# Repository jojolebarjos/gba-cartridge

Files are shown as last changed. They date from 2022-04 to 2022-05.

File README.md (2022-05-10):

# GameBoy Advance cartridge

This project is about making homebrew cartridges for the GameBoy Advance, using an FPGA (here a [TinyFPGA](https://tinyfpga.com/) BX).
Given the update frequency (and the fact that both falling-edges and rising-edges are meaningful), this is more convenient than bit-banging using some micro-controller.
A few experiments are available, some making use of an additional micro-controller (here an [Arduino Nano 33 BLE](https://store.arduino.cc/products/arduino-nano-33-ble)) for communication.

## Cartridge protocol

The cartridge has the following pins:

 * 1: `VCC`, at 3.3V.
 * 2: `PHI`, the physical clock, which can be configured (disabled, 4.19MHz, 8.38MHz, 16.78MHz). Disabled by default. See [waitstate control](https://www.akkit.org/info/gbatek.htm#gbasystemcontrol).
 * 3: `~WR`, write control.
 * 4: `~RD`, read control.
 * 5: `~CS`, select ROM.
 * 6-21: `AD`, address and data.
 * 22-29: `A`, address or data.
 * 30: `CS2`, select SRAM.
 * 31: `IRQ`, interrupt request. Can be left unconnected or grounded.
 * 32: `GND`, ground.

General comments about memory accesses:

 * Data format is always little endian, i.e. least significant byte is first.
 * Depending on the requested (virtual) address and operation, the GameBoy will either assume ROM or RAM when accessing the cartridge.
 * ROM data access is 16-bits, hence data is aligned on 2-bytes steps. This means the implicit least-significant bit of the address is always 0 (i.e. `A0..23` is the address divided by 2).
 * ARM instructions (32-bits) are slow to fetch. It is better to use THUMB instructions, or copy the code in WRAM.
 * GamePak accesses can be either sequential or non-sequential. The first access to a random location in ROM must be non-sequential.
 * The GameBoy will wait a few cycles when accessing memory. Up to 3 configurations can be used (useful if the cartridge has multiple ROM units with different physical properties). By default, it will assume 4 cycles for random access, and then 2 cycles for sequential access. See [waitstate control](https://www.akkit.org/info/gbatek.htm#gbasystemcontrol).
 * When doing ROM access, the `AD` bus is used in both direction. The cartridge should actively write only when both `~CS` and `~RD` are low.
 * When doing RAM access, the `AD` bus is used for the 16-bits address, and the 8-bits data is returned through `A16..23`. `~CS2` is used instead of `~CS`.

A read access from the ROM is done as follows:

 * On `~CS` falling-edge, the cartridge latches A0-A23 as address.
 * On `~RD` falling-edge, the cartridge fetches the data at latched address and outputs D0-D15. The output must be ready by next rising-edge of `~RD` (depends on waitstates).
 * On `~RD` rising-edge, the cartridge increments latched address by one (i.e. allow sequential read by just strobing `~RD`).
 * On `~CS` rising-edge, the transaction is done.

While it usually makes no sense to write to a ROM, the GameBoy will submit write commands in a similar fashion, toggling `~WR` instead.
In this project, we use that to let the software write back to the cartridge, for instance to report key input.

Therefore, a simple read-only GamePak ROM does not use `PHI`, `~WR`, `~CS2` and `IRQ`.

Cartridges that require more than 64K of storage will need to use bank switching to map more memory.
This topic has not been investigated in this project.

Relevant links:

 * References
   * https://github.com/gbadev-org/awesome-gbadev
   * https://www.gbadev.org/
   * https://www.akkit.org/info/gbatek.htm
   * https://problemkaputt.de/gbatek.htm
   * http://www.hardwarebook.info/Game_Pak
 * Blogs and websites
   * https://gekkio.fi/
     * https://gekkio.fi/files/gb-docs/gbctr.pdf
     * https://github.com/gekkio/gb-hardware
   * https://www.darkfader.net/gba/
     * http://files.darkfader.net/gba/files/cartridge.txt
   * https://reinerziegler.de.mirrors.gg8.se/GBA/gba.htm
   * http://kylehalladay.com/blog/tutorial/gba/2017/04/18/GBA-By-Example-4.html
   * https://fabiensanglard.net/another_world_polygons_GBA/
   * https://github.com/PeterLemon/GBA
 * Custom cartridges
   * https://github.com/uXeBoy/GBA
   * https://github.com/uXeBoy/GBArduboy
   * http://www.dl9sec.de/prj_gbacart.html
 * Cartridge reader
   * https://www.insidegadgets.com/2011/03/19/gbcartread-arduino-based-gameboy-cart-reader-%E2%80%93-part-1-read-the-rom/
   * https://douevenknow.us/post/68126856498/arduino-based-gba-rom-dumper-part-1
   * https://dragaosemchama.com/en/2015/12/gameboy-pak-reader-cartridge-header/
   * https://mgba.io/2015/10/20/dumping-the-undumped/
 * Multiboot-based
   * https://github.com/Shyri/gba-bt-hid
 * Old GameBoy, but still very interesting
   * https://dhole.github.io/post/gameboy_cartridge_emu_1/
   * https://retrocomputing.stackexchange.com/questions/11732/how-does-the-gameboys-memory-bank-switching-work
   * https://github.com/dwaq/Homebrew-Gameboy-Cartridge
   * https://www.insidegadgets.com/2018/04/18/building-a-2mb-mbc5-gameboy-cart-part-1-cpld-as-the-mbc-and-adding-flash-as-our-rom/
   * http://bitwise.bperki.com/2018/08/08/custom-game-boy-cartridge-project-update-1/
   * https://wiki.tauwasser.eu/view/MBC1
   * https://catskull.net/gameboy-boot-screen-logo.html

## Compiling a GameBoy Advance game

The GameBoy Advance features an ARM-based processor.
We will use [devkitPro](https://devkitpro.org/wiki/Main_Page) to compile binaries.

The most straightforward approach is to use the [Docker image](https://github.com/devkitPro/docker).
We share the local folder with the container, to avoid unnecessary copies.

```
# Run in interactive mode
docker run -ti -v ${PWD}:/rom devkitpro/devkitarm
# On Windows: docker run -ti -v %cd%:/rom devkitpro/devkitarm

# Add compiler binaries to path
export PATH="/opt/devkitpro/devkitARM/bin/:$PATH"

# Go to shared folder and build files
cd /rom/
make
```

Links related to GBA software development:

 * https://www.coranac.com/tonc/text/toc.htm
 * https://devkitpro.org/wiki/Getting_Started
 * https://github.com/devkitPro/docker
 * https://github.com/devkitPro/gba-examples
 * http://kylehalladay.com/blog/tutorial/gba/2017/03/28/GBA-By-Example-1.html
 * https://www.coranac.com/tonc/text/setup.htm#sec-dkp
 * https://www.akkit.org/info/gbatek.htm#gbakeypadinput
 * https://www.coranac.com/tonc/text/keys.htm
 * https://github.com/felixjones/gba-plusplus

Emulators and GameBoy implementations:

 * https://mgba.io/
 * https://github.com/RobertPeip/FPGBA
 * https://github.com/AntonioND/giibiiadvance
 * https://mitxela.com/projects/swotgb/about

## Development PCB

In order to have a flexible playground, a custom-made PCB has been designed using [KiCad](https://www.kicad.org/) and ordered on [JLCPCB](https://jlcpcb.com/).
[This](https://www.aliexpress.com/item/1005003412771520.html) cheap cartridge header can be soldered to connect an actual cartridge, if needed.
A simple casing has been designed using [FreeCAD](https://www.freecadweb.org/) and 3D-printed (resin) to properly fit the GameBoy Advance.
Depending on whether a GameBoy Advance and/or a cartridge is used, the FPGA can have various roles.

 * The 32 pins of the cartridge are forwarded from the GameBoy to the cartridge.
 * Two sets of connectors are available to intercept (or drive) the pins: a 2x16 header for generic usage, and a 2x14 header designed to hold the TinyFPGA BX.
 * A dedicated header is available to configure power supply.
 * `A` is not exposed to the TinyFPGA BX, as there are not enough pins. Note that some GPIO pins are exposed as pads by the FPGA, but this is not convenient for this project.
 * Instead, some pins are exposed as "extra", and can be used either for external communication (e.g. SPI) or connected to `A` to extend the address space.
 * Use ENIG finish (i.e. *not* HASL), for more strength.
 * In order to fit in the opening, a thickness of 0.8mm should be used (as the casing already takes roughly 1mm).

See the [schema](pcb.sch.pdf) for more details.

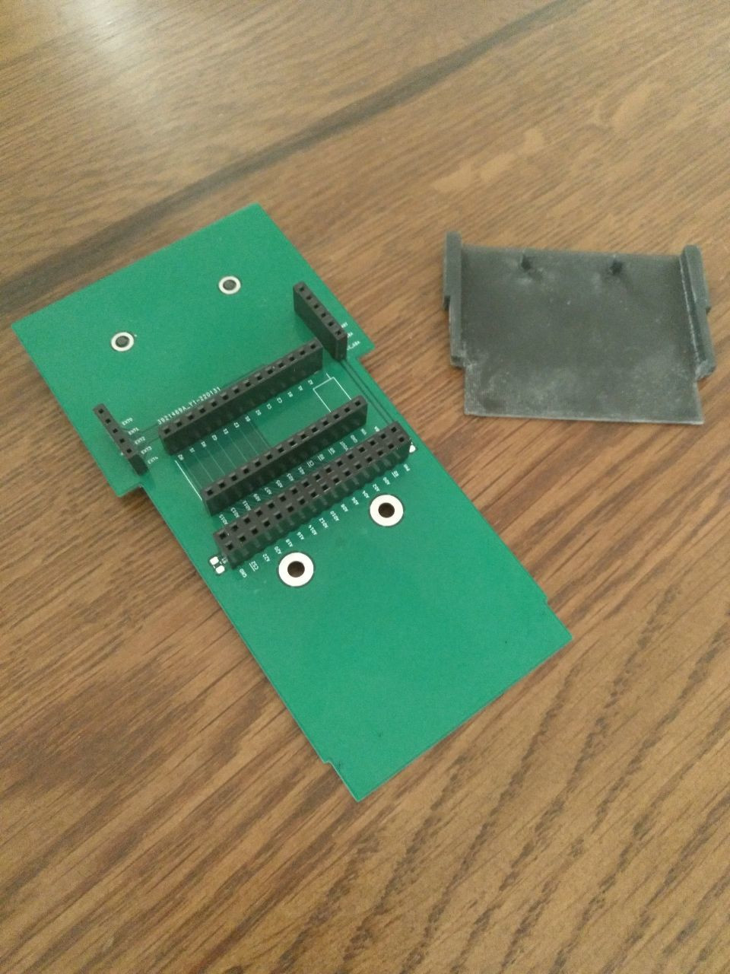
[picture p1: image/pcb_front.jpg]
PCB (front)


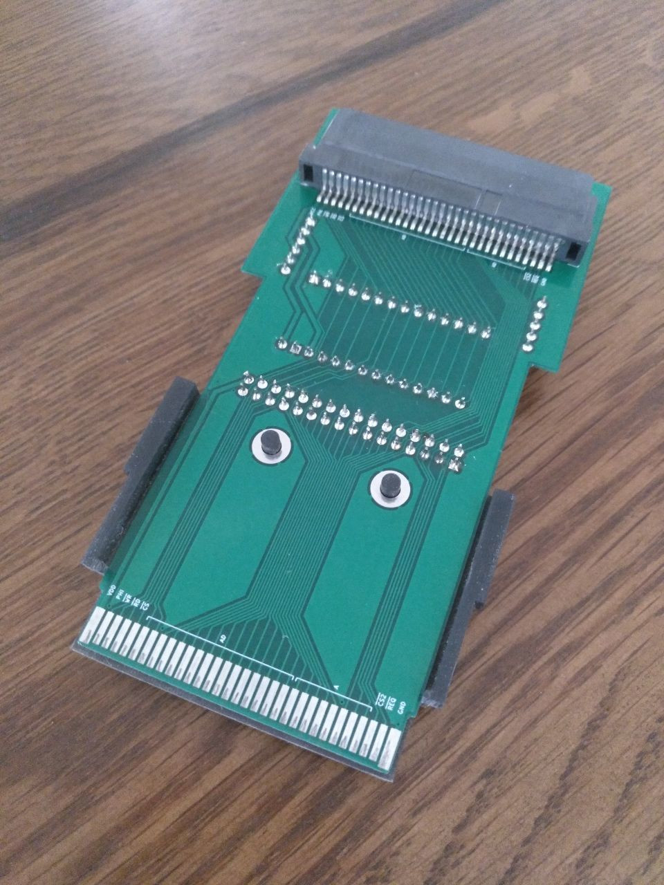
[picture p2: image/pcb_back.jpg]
PCB (back)


## Getting started with TinyFPGA BX

As described in the [User Guide](https://tinyfpga.com/bx/guide.html), install [APIO](https://github.com/FPGAWARS/apio):

```
conda create -n fpga python=3.7
activate fpga
pip install apio==0.4.0b5 tinyprog
apio install system scons icestorm iverilog
```

Connect the board and run:

```
apio install drivers
apio drivers --serial-enable
```

Reconnect the board, and check that the device is recognized.
Windows might take a few seconds to actually detect and properly setup the serial device.

```
apio system --lsserial
```

Make sure the board is up-to-date:

```
tinyprog --update-bootloader
```

For better integration, use [Atom](https://atom.io/) and install the `apio-ide` package.
Note that you should run Atom inside the Conda environment, so that paths are properly set up:

```
atom --new-instance
```

Using the [default template](https://github.com/tinyfpga/TinyFPGA-BX/tree/master/apio_template), you can quickly start developing the TinyFPGA.

Note that you can upload the code by calling `tinyprog` directly:

```
tinyprog --program hardware.bin
```

The `apio-ide` package provide shortcuts for the most common operations, i.e. build and program.
Use `F8` to show the compilation log after a successful build.

Links:

 * https://tinyfpga.com/
 * http://www.clifford.at/icestorm/
 * https://www.youtube.com/watch?v=ZNunxg7o8l0
 * https://hackaday.io/project/159191-fpga-bootcamp-1
 * https://github.com/YosysHQ/nextpnr

## Experiments

A few simple experiments have been made until now.

### Cartridge dump

An Arduino Nano 33 BLE is connected to a TinyFPGA BX over SPI.

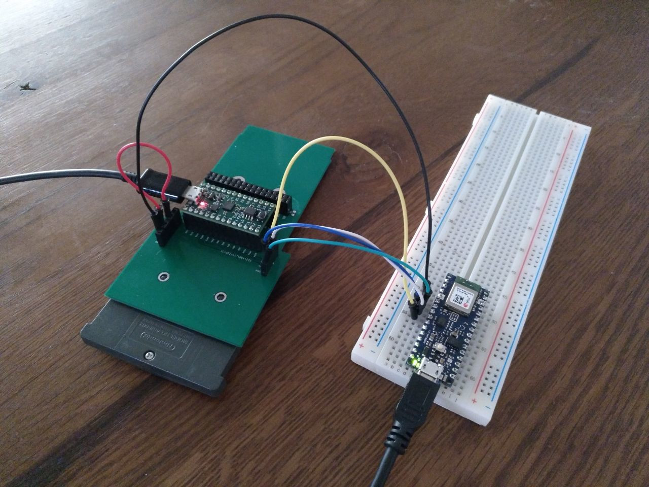
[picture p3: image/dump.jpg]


| Name | Arduino Nano 33 BLE | Wire | Board | TinyFPGA BX |
| ---- | ---- | ---- | ---- | ---- |
| GND | GND | black | GND | GND | GND |
| MISO | D2 (2) | green | EXT0 | 1 (A2) |
| MOSI | D3 (3) | blue | EXT1 | 2 (A1) |
| SCK | D4 (4) | white | EXT2 | 3 (B1) |
| SS | D5 (5) | yellow | EXT3 | 4 (C2) |

The cartridge is powered by the TinyFPGA BX, i.e. `VCC_CART` is connected to `VOUT`.

This is a naive implementation of the above-mentioned protocol:

 * The FPGA toggles `~CS` and `~RD`, writes the address and reads the output through `AD`. Note that, as `A` is ignored, only the first 131072 can be read.
 * The Arduino acts as a bridge, communicating with the FPGA using SPI and with the computer using USB.
 * A Python script sends the commands and dumps the content to a binary file.

Note that this approach does not handle any memory bank.
Therefore, it cannot be used as-is to dump a whole cartridge.

See [`./experiments/dump/`](./dump/) for more details.

### Read-only cartridge

The TinyFPGA BX acts as a read-only ROM cartridge.
A simple "game" is provided, where a white dot is moved using the arrows.

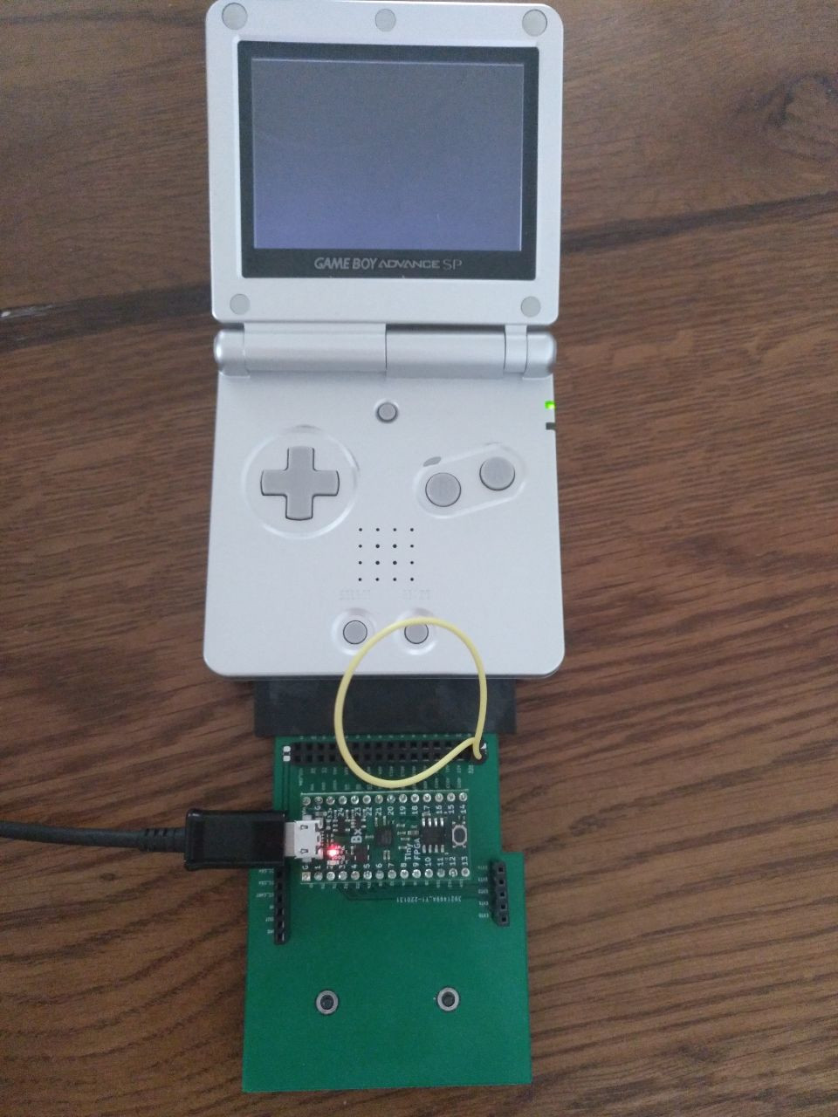
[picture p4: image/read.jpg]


See [`./experiments/read/`](./read/) for more details.

### Read-write

The TinyFPGA BX acts as a writable ROM cartridge.
A simple "game" is provided, where buttons are written at each frame to the cartridge memory.

See [`./experiments/write/`](./write/) for more details.

### USB gamepad

The TinyFPGA BX acts as a writable ROM cartridge.
A simple "game" is provided, where buttons are written at each frame to the cartridge memory.
This information is then forwarded to an Arduino Nano 33 BLE, which is recognized as a HID gamepad.

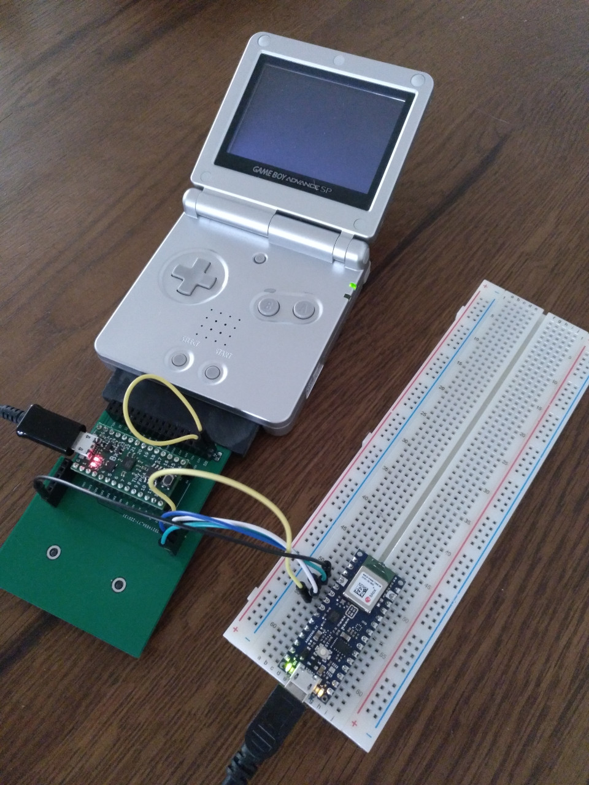
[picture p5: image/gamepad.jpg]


TODO: use HID over USB/BLE

TODO: use interrupts on GBA (and sleep when no button is pressed)

TODO: make FPGA the SPI master, or use interrupts to let the Arduino communicate only when needed

See [`./experiments/gamepad/`](./gamepad/) for more details.

### Direct Memory Access

...

http://problemkaputt.de/gbatek-gba-dma-transfers.htm
https://gbdev.gg8.se/wiki/articles/Video_Display
https://austinjadams.com/blog/autograding-gba-dma/
https://badd10de.dev/notes/gba-programming.html

See [`./experiments/dma/`](./dma/) for more details.

### VGA

The GBA has a TFT color LCD that is 240 x 160 pixels in size and has a refresh rate of exactly 280896 cpu cycles per frame, or around 59.73 hz.
Most GBA programs will need to structure themselves around this refresh rate.
The LCD can display 15-bit RGB colors (0bxbbbbbgggggrrrrr).

TODO:
 * Use backbuffer (with palette) mode 4, to acquire next frame during previous one is drawn
 * VGA is an analog signal, with 5 (+GND) relevant pins: R, G, B, H-Sync, V-Sync
 * We can naively connect these to digital inputs, effectively displaying only 8 colors
 * We can also use an analog-to-digital serial converter, if FPGA is fast enough
 * https://electronics.stackexchange.com/questions/134674/how-vga-monitor-detects-video-resolution
 * Need 3:2 resolution, so maybe use 320x200 and trim 20 pixels horizontally? https://www.videotechnology.com/0904/formats.html

The closest standard mode is 720x480 @60Hz RGB 4:4:4

 * https://en.wikipedia.org/wiki/Video_Graphics_Array
 * https://en.wikipedia.org/wiki/HDMI
 * https://www.youtube.com/watch?v=l7rce6IQDWs&ab_channel=BenEater
 * http://tinyvga.com/vga-timing
 * https://ez.analog.com/cfs-file/__key/telligent-evolution-components-attachments/00-317-00-00-00-05-21-37/HDMISpecification13a.pdf
 * https://forum.digikey.com/t/vga-controller-vhdl/12794

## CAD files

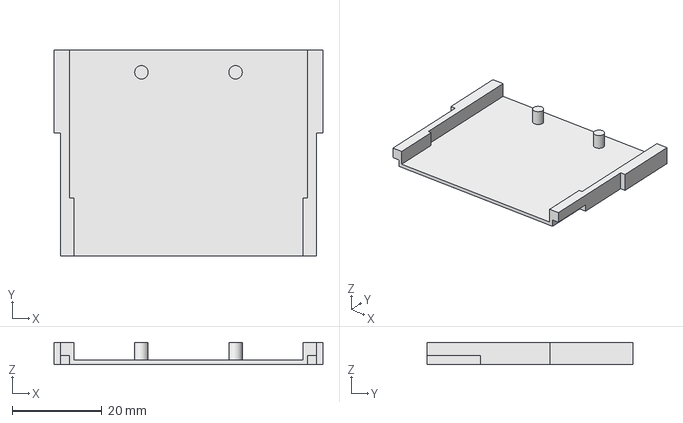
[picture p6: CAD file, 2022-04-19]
case/case.FCStd
60.0 x 46.0 x 5.00 mm

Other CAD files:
case/case.stl

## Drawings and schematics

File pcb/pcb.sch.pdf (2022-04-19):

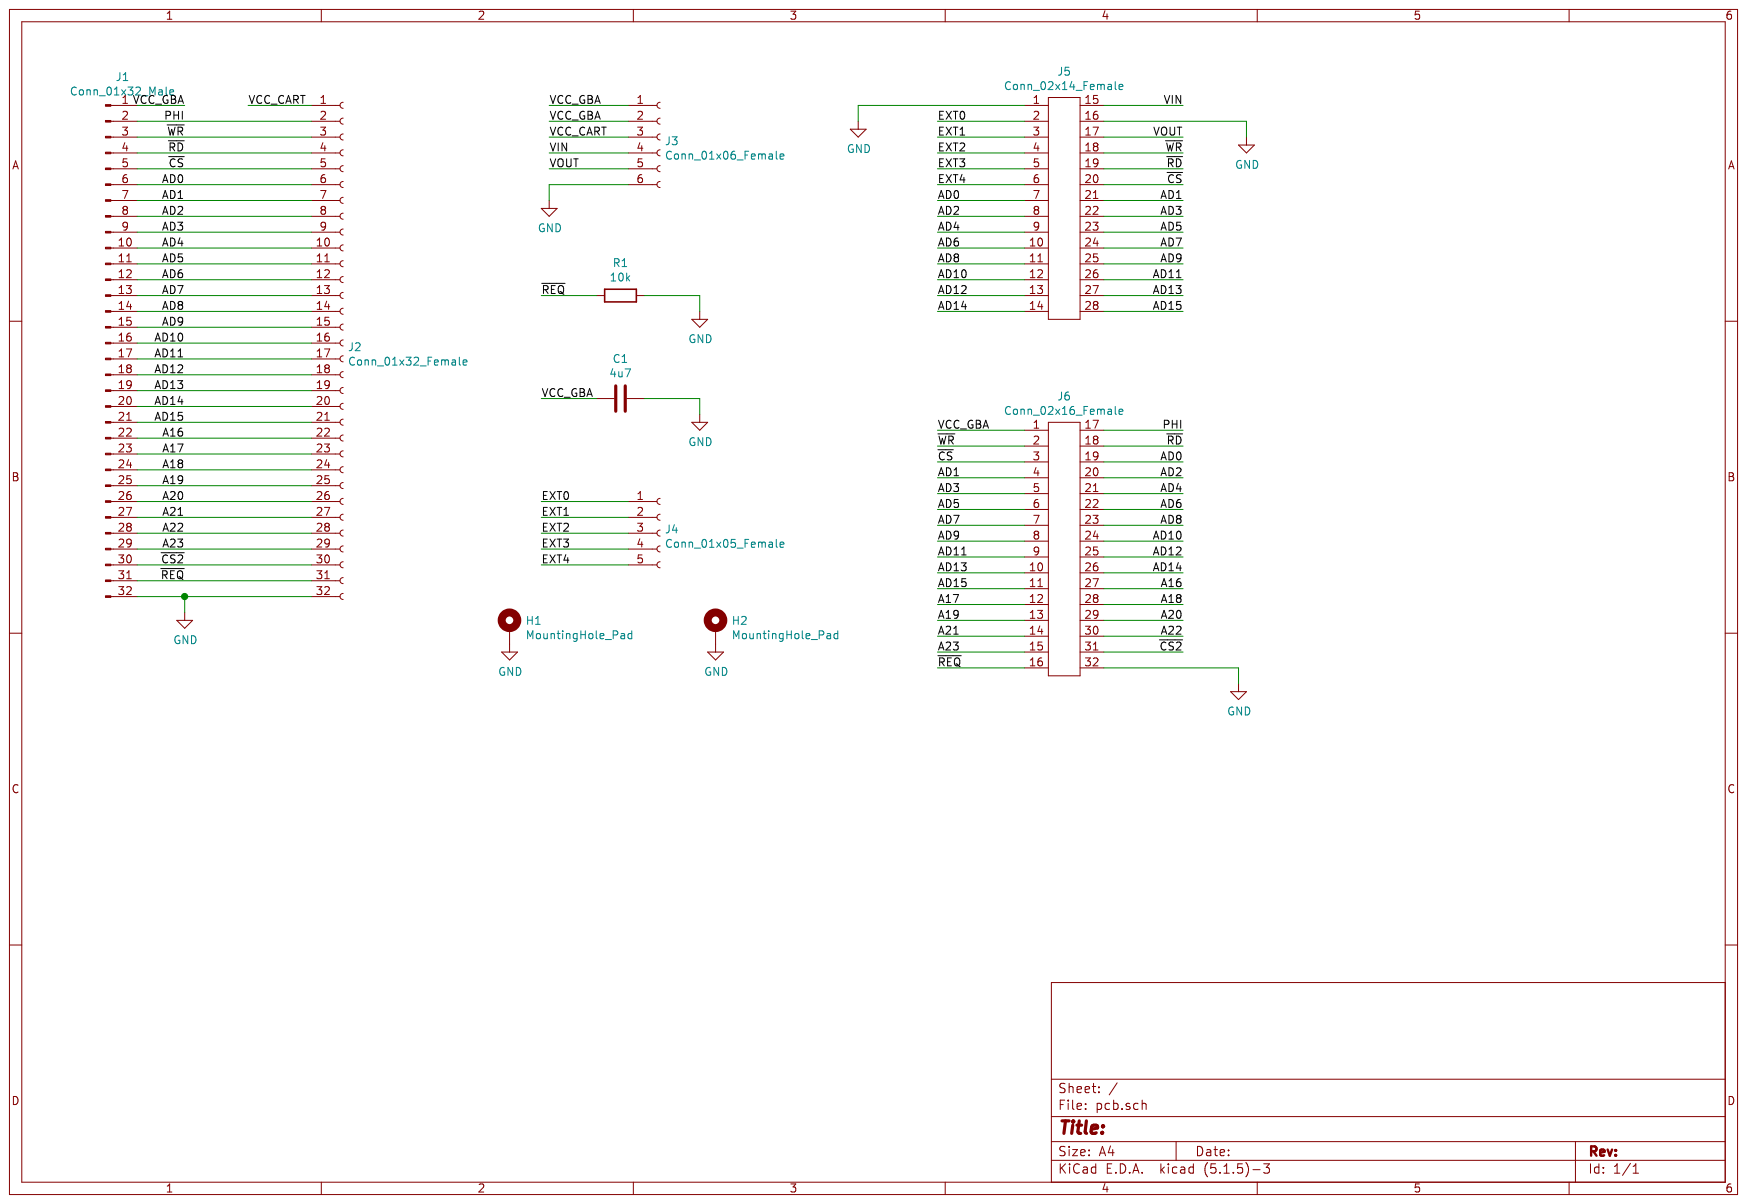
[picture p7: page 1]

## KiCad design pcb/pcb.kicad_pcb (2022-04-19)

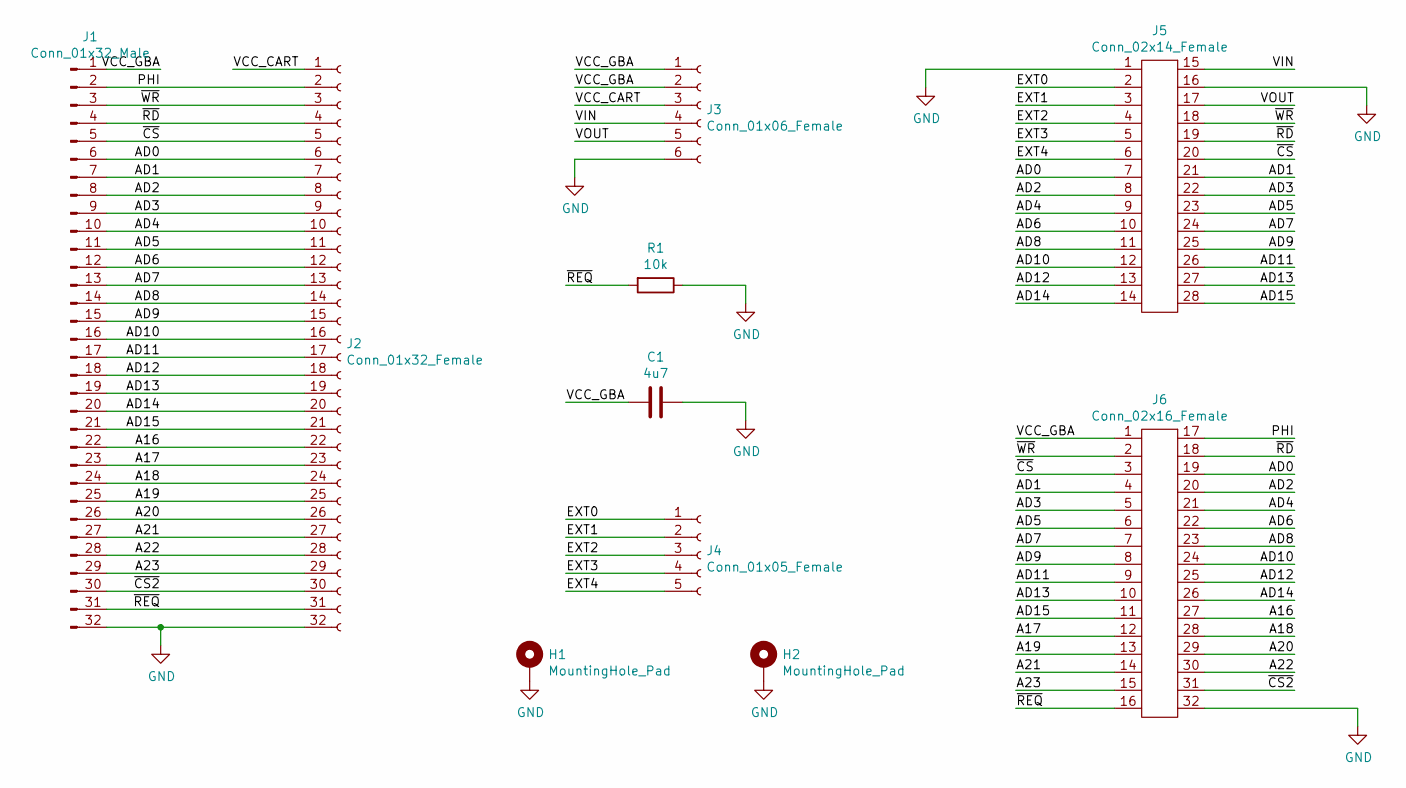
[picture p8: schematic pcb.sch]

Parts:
C1: 4u7; C_0805_2012Metric_Pad1.15x1.40mm_HandSolder
H1, H2: MountingHole_Pad; MountingHole_3.2mm_M3_Pad
J1: Conn_01x32_Male; GBA
J2: Conn_01x32_Female; CART
J3: Conn_01x06_Female; PinHeader_Power
J4: Conn_01x05_Female; PinHeader_Extra
J5: Conn_02x14_Female; PinHeader_TinyFPGA_BX
J6: Conn_02x16_Female; PinHeader_Secondary
R1: 10k; R_0805_2012Metric_Pad1.15x1.40mm_HandSolder

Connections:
/A16: J1.22, J2.22, J6.27
/A17: J1.23, J2.23, J6.12
/A18: J1.24, J2.24, J6.28
/A19: J1.25, J2.25, J6.13
/A20: J1.26, J2.26, J6.29
/A21: J1.27, J2.27, J6.14
/A22: J1.28, J2.28, J6.30
/A23: J1.29, J2.29, J6.15
/AD0: J1.6, J2.6, J5.7, J6.19
/AD1: J1.7, J2.7, J5.21, J6.4
/AD2: J1.8, J2.8, J5.8, J6.20
/AD3: J1.9, J2.9, J5.22, J6.5
/AD4: J1.10, J2.10, J5.9, J6.21
/AD5: J1.11, J2.11, J5.23, J6.6
/AD6: J1.12, J2.12, J5.10, J6.22
/AD7: J1.13, J2.13, J5.24, J6.7
/AD8: J1.14, J2.14, J5.11, J6.23
/AD9: J1.15, J2.15, J5.25, J6.8
/AD10: J1.16, J2.16, J5.12, J6.24
/AD11: J1.17, J2.17, J5.26, J6.9
/AD12: J1.18, J2.18, J5.13, J6.25
/AD13: J1.19, J2.19, J5.27, J6.10
/AD14: J1.20, J2.20, J5.14, J6.26
/AD15: J1.21, J2.21, J5.28, J6.11
/EXT0: J4.1, J5.2
/EXT1: J4.2, J5.3
/EXT2: J4.3, J5.4
/EXT3: J4.4, J5.5
/EXT4: J4.5, J5.6
/PHI: J1.2, J2.2, J6.17
/VCC_CART: J2.1, J3.3
/VCC_GBA: C1.2, J1.1, J3.1, J3.2, J6.1
/VIN: J3.4, J5.15
/VOUT: J3.5, J5.17
/~CS: J1.5, J2.5, J5.20, J6.3
/~CS2: J1.30, J2.30, J6.31
/~RD: J1.4, J2.4, J5.19, J6.18
/~REQ: J1.31, J2.31, J6.16, R1.2
/~WR: J1.3, J2.3, J5.18, J6.2
GND: C1.1, H1.1, H2.1, J1.32, J2.32, J3.6, J5.1, J5.16, J6.32, R1.1

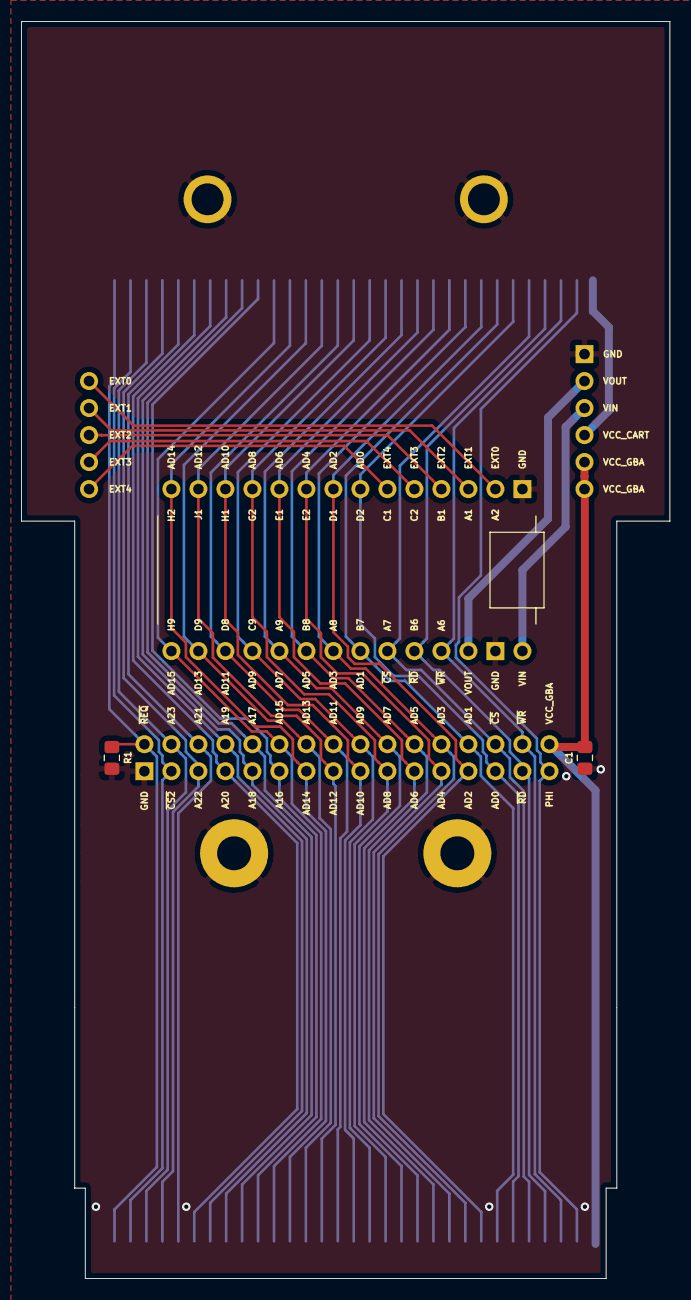
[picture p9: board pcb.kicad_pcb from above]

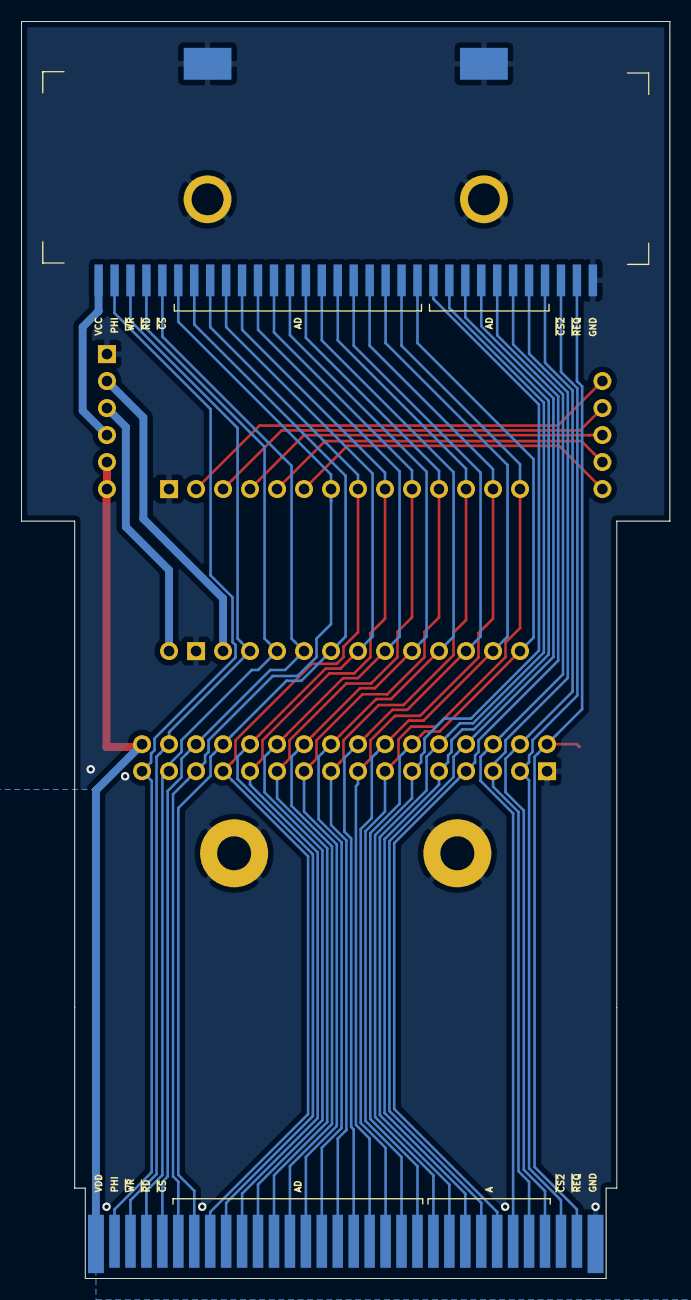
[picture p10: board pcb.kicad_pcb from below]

Board: 2 copper layers, 61.0 x 118.2 mm, 10 parts (2 on the bottom side), 40 nets.

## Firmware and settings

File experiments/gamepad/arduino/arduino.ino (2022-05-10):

// TODO use https://os.mbed.com/docs/mbed-os/v6.15/apis/spi.html instead

// Pins
#define MISO 2
#define MOSI 3
#define SCK 4
#define SS 5

// GameBoy Advance key state
uint16_t keyinput = 0x0000;

void setup() {

  // Connect to USB serial port
  Serial.begin(9600);
  while (!Serial);

  // Configure pins
  pinMode(MISO, INPUT);
  pinMode(MOSI, OUTPUT);
  pinMode(SCK, OUTPUT);
  pinMode(SS, OUTPUT);
  digitalWrite(MOSI, LOW);
  digitalWrite(SCK, LOW);
  digitalWrite(SS, HIGH);
}

uint16_t transfer(uint16_t in) {

  // Set Slave Select to low, to start message
  digitalWrite(SCK, LOW);
  digitalWrite(LED_BUILTIN, LOW);
  digitalWrite(SS, LOW);

  // Exchange each bit, most significant bit first
  int out = 0;
  for (int b = 15; b >= 0; --b) {

    // Write bit at Serial Clock falling edge
    int b_in = (in >> b) & 1;
    digitalWrite(MOSI, b_in ? HIGH : LOW);

    // Wait half-cycle
    delay(1);

    // Rise Serial Clock
    digitalWrite(SCK, HIGH);
    digitalWrite(LED_BUILTIN, HIGH);

    // Read bit at rising edge
    int b_out = digitalRead(MISO) == HIGH ? 1 : 0;
    out = (out << 1) | b_out;

    // Wait half-cycle
    delay(1);

    // Fall Serial Clock
    digitalWrite(SCK, LOW);
    digitalWrite(LED_BUILTIN, LOW);
  }

  // Set Slave Select to high, to end message
  digitalWrite(SS, HIGH);
  return out;
}

void loop() {

  // Read from SPI
  // Note: slave ignores the actual data, so let us just use zero
  uint16_t out = transfer(0x0000);

  // If state did change, notify
  if (out != keyinput) {
    keyinput = out;
    // TODO do an actual USB/BLE gamepad interface
    Serial.println(keyinput);
  }

  // Wait a bit, to avoid spam
  delay(2);
}

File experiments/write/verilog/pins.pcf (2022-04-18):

###############################################################################
#
# TinyFPGA BX constraint file (.pcf)
#
###############################################################################
#
# Copyright (c) 2018, Luke Valenty
# All rights reserved.
#
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
# THIS SOFTWARE IS PROVIDED BY THE COPYRIGHT HOLDERS AND CONTRIBUTORS "AS IS" AND
# ANY EXPRESS OR IMPLIED WARRANTIES, INCLUDING, BUT NOT LIMITED TO, THE IMPLIED
# WARRANTIES OF MERCHANTABILITY AND FITNESS FOR A PARTICULAR PURPOSE ARE
# DISCLAIMED. IN NO EVENT SHALL THE COPYRIGHT OWNER OR CONTRIBUTORS BE LIABLE FOR
# ANY DIRECT, INDIRECT, INCIDENTAL, SPECIAL, EXEMPLARY, OR CONSEQUENTIAL DAMAGES
# (INCLUDING, BUT NOT LIMITED TO, PROCUREMENT OF SUBSTITUTE GOODS OR SERVICES;
# LOSS OF USE, DATA, OR PROFITS; OR BUSINESS INTERRUPTION) HOWEVER CAUSED AND
# ON ANY THEORY OF LIABILITY, WHETHER IN CONTRACT, STRICT LIABILITY, OR TORT
# (INCLUDING NEGLIGENCE OR OTHERWISE) ARISING IN ANY WAY OUT OF THE USE OF THIS
# SOFTWARE, EVEN IF ADVISED OF THE POSSIBILITY OF SUCH DAMAGE.
#
# The views and conclusions contained in the software and documentation are those
# of the authors and should not be interpreted as representing official policies,
# either expressed or implied, of the <project name> project.
#
###############################################################################

####
# TinyFPGA BX information: https://github.com/tinyfpga/TinyFPGA-BX/
####

# Left side of board
set_io --warn-no-port PIN_1 A2
set_io --warn-no-port PIN_2 A1
set_io --warn-no-port PIN_3 B1
set_io --warn-no-port PIN_4 C2
set_io --warn-no-port PIN_5 C1
set_io --warn-no-port PIN_6 D2
set_io --warn-no-port PIN_7 D1
set_io --warn-no-port PIN_8 E2
set_io --warn-no-port PIN_9 E1
set_io --warn-no-port PIN_10 G2
set_io --warn-no-port PIN_11 H1
set_io --warn-no-port PIN_12 J1
set_io --warn-no-port PIN_13 H2

# Right side of board
set_io --warn-no-port PIN_14 H9
set_io --warn-no-port PIN_15 D9
set_io --warn-no-port PIN_16 D8
set_io --warn-no-port PIN_17 C9
set_io --warn-no-port PIN_18 A9
set_io --warn-no-port PIN_19 B8
set_io --warn-no-port PIN_20 A8
set_io --warn-no-port PIN_21 B7
set_io --warn-no-port PIN_22 A7
set_io --warn-no-port PIN_23 B6
set_io --warn-no-port PIN_24 A6

# SPI flash interface on bottom of board
set_io --warn-no-port SPI_SS F7
set_io --warn-no-port SPI_SCK G7
set_io --warn-no-port SPI_IO0 G6
set_io --warn-no-port SPI_IO1 H7
set_io --warn-no-port SPI_IO2 H4
set_io --warn-no-port SPI_IO3 J8

# General purpose pins on bottom of board
set_io --warn-no-port PIN_25 G1
set_io --warn-no-port PIN_26 J3
set_io --warn-no-port PIN_27 J4
set_io --warn-no-port PIN_28 G9
set_io --warn-no-port PIN_29 J9
set_io --warn-no-port PIN_30 E8
set_io --warn-no-port PIN_31 J2

# LED
set_io --warn-no-port LED B3

# USB
set_io --warn-no-port USBP B4
set_io --warn-no-port USBN A4
set_io --warn-no-port USBPU A3

# 16MHz clock
set_io --warn-no-port CLK B2 # input

# Cartridge
set_io --warn-no-port AD[0] D2 # PIN_6
set_io --warn-no-port AD[2] D1 # PIN_7
set_io --warn-no-port AD[4] E2 # PIN_8
set_io --warn-no-port AD[6] E1 # PIN_9
set_io --warn-no-port AD[8] G2 # PIN_10
set_io --warn-no-port AD[10] H1 # PIN_11
set_io --warn-no-port AD[12] J1 # PIN_12
set_io --warn-no-port AD[14] H2 # PIN_13
set_io --warn-no-port AD[15] H9 # PIN_14
set_io --warn-no-port AD[13] D9 # PIN_15
set_io --warn-no-port AD[11] D8 # PIN_16
set_io --warn-no-port AD[9] C9 # PIN_17
set_io --warn-no-port AD[7] A9 # PIN_18
set_io --warn-no-port AD[5] B8 # PIN_19
set_io --warn-no-port AD[3] A8 # PIN_20
set_io --warn-no-port AD[1] B7 # PIN_21
set_io --warn-no-port CS A7 # PIN_22
set_io --warn-no-port RD B6 # PIN_23
set_io --warn-no-port WR A6 # PIN_24

# SPI
set_io --warn-no-port MISO A2 # PIN_1 -> EXT0
set_io --warn-no-port MOSI A1 # PIN_2 -> EXT1
set_io --warn-no-port SCK B1 # PIN_3 -> EXT2
set_io --warn-no-port SS C2 # PIN_4 -> EXT3

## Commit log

2022-01-24 Add early draft
    [pcb.kicad_pcb, pcb.sch]
2022-01-27 Move headers to the other side
    [pcb.kicad_pcb]
2022-04-18 Toward SPI-based cartridge reader
2022-04-19 Push latest version
    [pcb.kicad_pcb]
2022-04-19 Add Gerber files
    [pcb-B_Cu.gbr, pcb-B_Mask.gbr, pcb-B_Paste.gbr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]
2022-04-19 Add 3D casing model
    [case.FCStd, case.stl]
